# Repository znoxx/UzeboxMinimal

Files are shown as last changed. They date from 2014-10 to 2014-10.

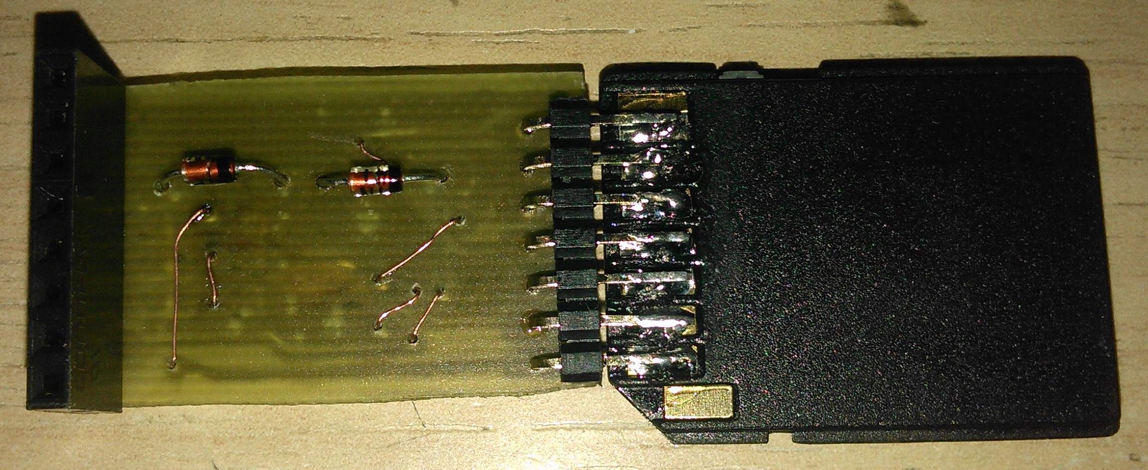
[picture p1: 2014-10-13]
sdcard/schematics/sdconnection2.jpg

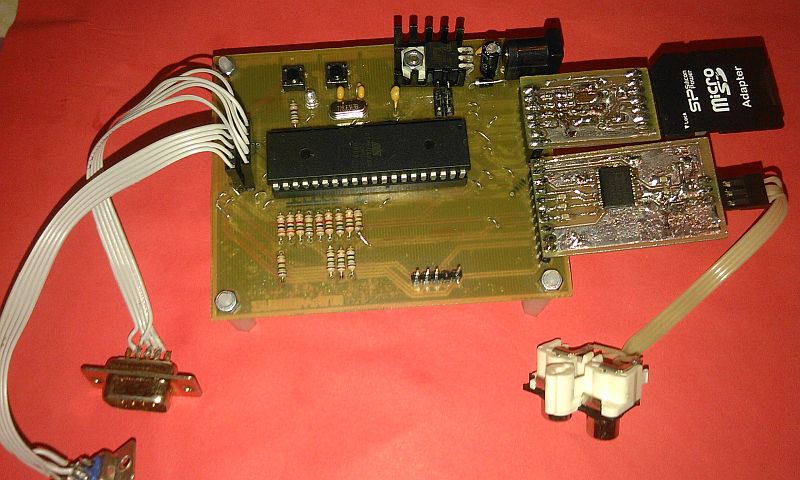
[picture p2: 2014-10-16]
_some_photos/assembled.jpg

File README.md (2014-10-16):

UzeboxMinimal
=============

Uzebox minimal design. The goal - to creat reprodusable modular design with minimal set of components.
Original project is located at http://uzebox.org

Update 16-Oct-2014 (2): Created simple MIDI expansion board. Never tested, since no MIDI devices owned :). See readme.txt inside midi subdir.
Actually project finalized.

Update 16-Oct-2014: Added video extension for AD725, same structure as in other projects (eagle,schematics,toner-transfer).
Also untested version removed.
Currently version is fully tested and confirmed working.

Update 13-Oct-2014: Added SD Card adapter.
eagle - To be opened with Eagle Cad 7.x.
schematics - Schematics, top jumpers and placement. Also an example of microSD adapter soldering. 
toner-transfer - Ready-to-print file for toner transfer. Have fun!
For best results:
Non-SDHC cards. In case using 2GB cards or bigger, create first partition about 256Mb. 
This is more, than enough for UzeBOX roms. 
Most important part partition should be FAT16 with 16K clusters.

Update 04-Oct-2014: This version is fixed somehow and soldered. Appears to be working.
Files (in mainboard dir):	
eagle - To be opened with Eagle Cad 7.x.
schematics - Schematics, top jumpers and placement
scart - connection via SCART
toner-transfer - Ready-to-print file for toner transfer. Have fun!

Update 01-Oct-2014: Current version is NOT tested in a "wild". Placed to share with forum members.
Files (not-tested dir):	
*.brd and *.sch - To be opened with Eagle Cad 7.x
schematics.pdf - Schematics
board-bottom.pdf - For toner transfer. Must be validated for correct size after/before print. Please check schematics/board layout for jumpers on top.

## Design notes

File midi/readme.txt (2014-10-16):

This midi extension daughterboard was never tested in wild.
Double check schematics with F2 revision of original UzeBox at http://belogic.com/uzebox/downloads.htm before crafting.
Feel free to report any issues.

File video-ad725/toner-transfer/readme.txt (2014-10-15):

After toner transfer, please remove toner trace near board connector to avoid short circuit.
Or, cut the paper exactly by dimensions.

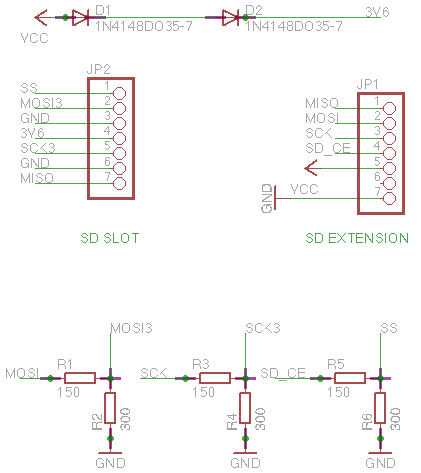
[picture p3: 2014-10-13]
sdcard/schematics/schematics.png

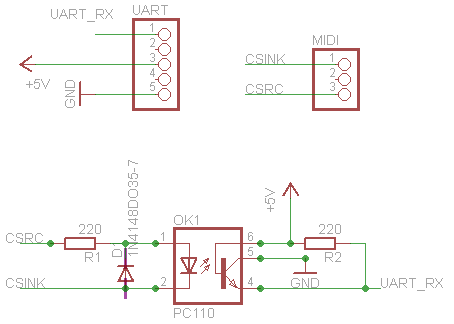
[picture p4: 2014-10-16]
midi/schematic/midi.png

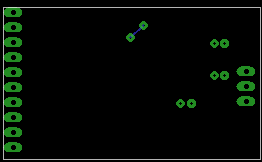
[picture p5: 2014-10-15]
video-ad725/schematics/jumpers.png

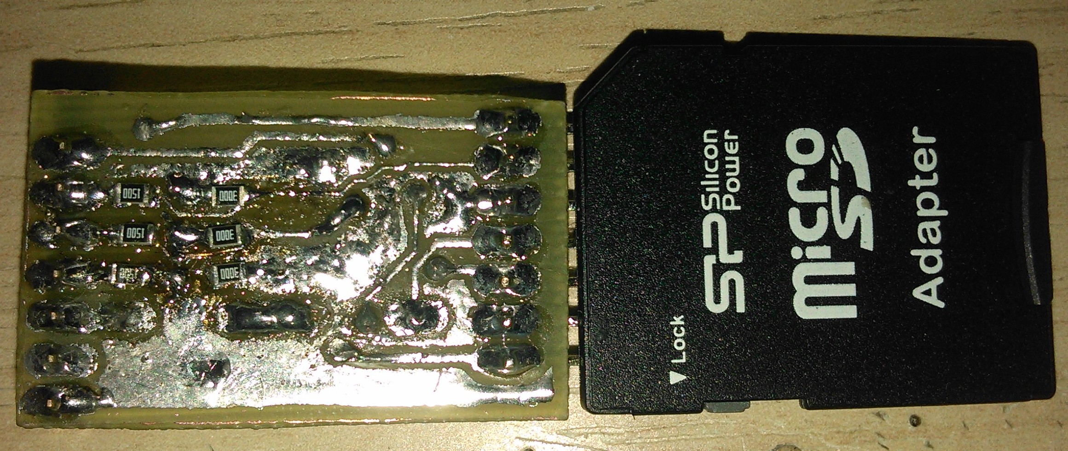
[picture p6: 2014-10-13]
sdcard/schematics/sdconnection1.jpg

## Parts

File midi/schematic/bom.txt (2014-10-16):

Part	Value	Type
D1	1N4148	Diode DO35-7
"R1,R2"	220 Ohm	Resistor 0.125w
OK1	PC110	Optocoupler DIL06
UART 	x10 male pinhead	2.54 mm
MIDI	"x3 male pinhead, central connector cut"	2.54 mm

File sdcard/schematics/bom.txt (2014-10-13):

Partlist

Exported from sdcard.brd at 13/10/14 22:13

EAGLE Version 7.1.0 Copyright (c) 1988-2014 CadSoft

Assembly variant: 

Part     Value          Package  Library  Position (mm)         Orientation

D1       1N4148DO35-7   DO35-7   diode    (9.8429 64.370853125) R180
D2       1N4148DO35-7   DO35-7   diode    (20.311653125 64.374278125) R180
JP1                     1X07     pinhead  (2.468659375 66.847653125) R270
JP2                     1X07     pinhead  (29.818525 69.15326875) R270
R1       150            R0805    resistor (6.523165625 71.8643625) R0
R2       300            R0805    resistor (12.27610625 71.891471875) R0
R3       150            R0805    resistor (6.53596875 69.4378125) R0
R4       300            R0805    resistor (12.279684375 69.417925) R0
R5       150            R0805    resistor (6.46664375 66.8897875) R0
R6       300            R0805    resistor (12.514678125 66.8897875) R180

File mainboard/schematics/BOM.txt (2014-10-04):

C1	Capacitor ceramic	330nf	1	
"C2,C3"	Capacitor ceramic	22pf	2	
C5	Capacitor ceramic	100nf	1	
C4	Capacitor electrolit	100mf	1	
IC1	ATMEGA644-20PU			
IC2	7805 Regulator		1	
"JP1,JP2,JP3,JP4,JP5"	PLS-40 connector		1	 cut it to pieces :)
LED1	LED	3mm	1	
Q1	Crystal	28.63636 Mhz	1	
D1	Diode	1N4001 	1	
J1	Powerjack			
"R1,R4,R12"	Resistor 0.125w	3K	4	
"R2,R5,R7"	Resistor 0.125w	1.5K	3	
"R3,R6,R8,R13"	Resistor 0.125w	750 Ohm	4	
R14	Resistor 0.125w	160 Ohm	1	
"R9,R10,R11"	Resistor 0.125w	75 Ohm	4	
"S1,S2"	Button		2

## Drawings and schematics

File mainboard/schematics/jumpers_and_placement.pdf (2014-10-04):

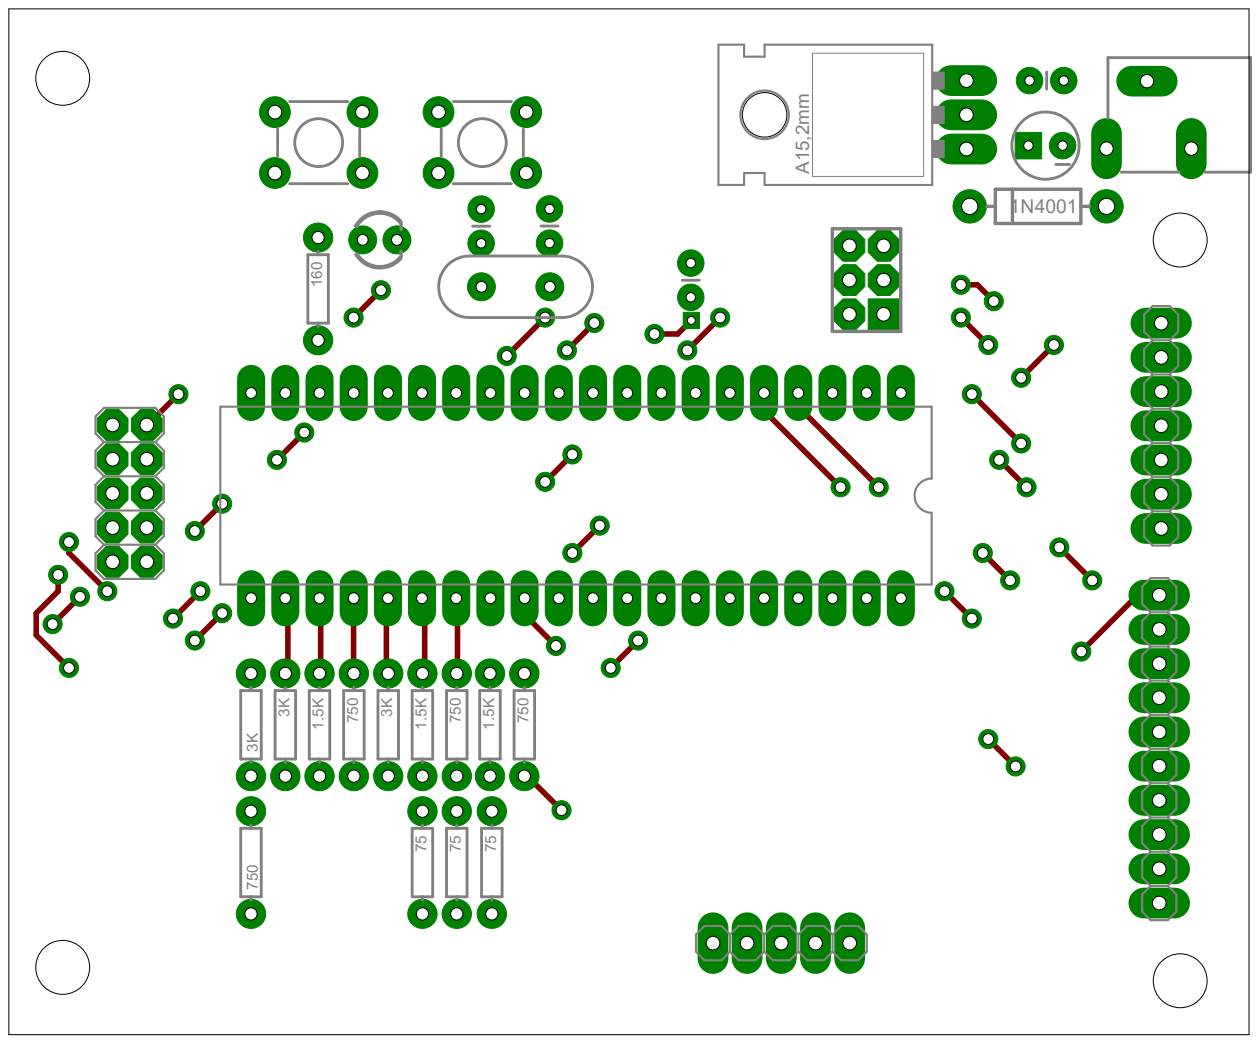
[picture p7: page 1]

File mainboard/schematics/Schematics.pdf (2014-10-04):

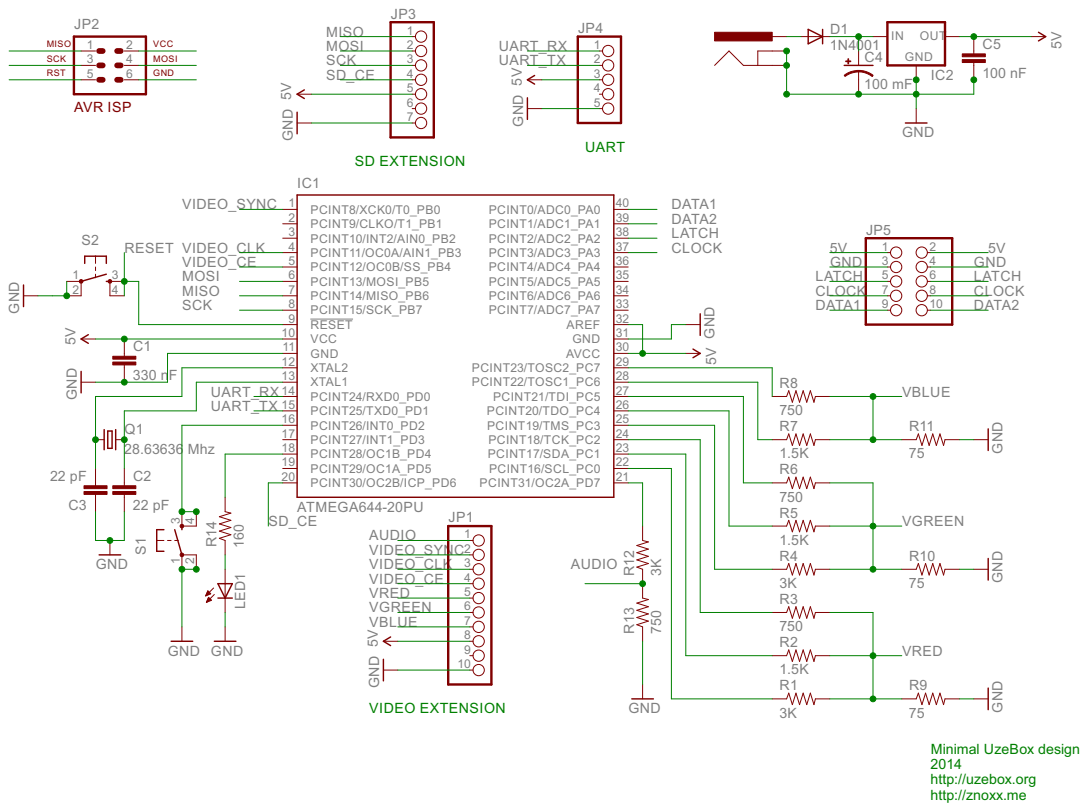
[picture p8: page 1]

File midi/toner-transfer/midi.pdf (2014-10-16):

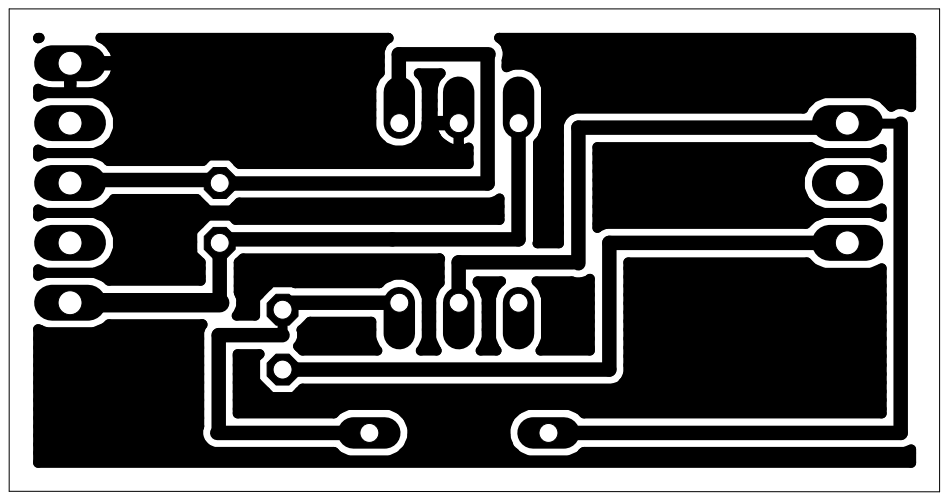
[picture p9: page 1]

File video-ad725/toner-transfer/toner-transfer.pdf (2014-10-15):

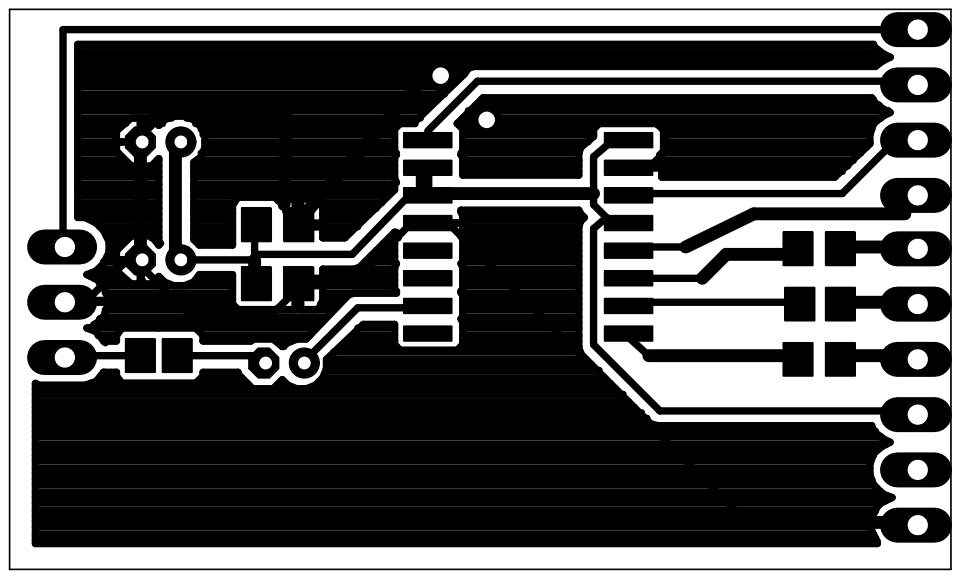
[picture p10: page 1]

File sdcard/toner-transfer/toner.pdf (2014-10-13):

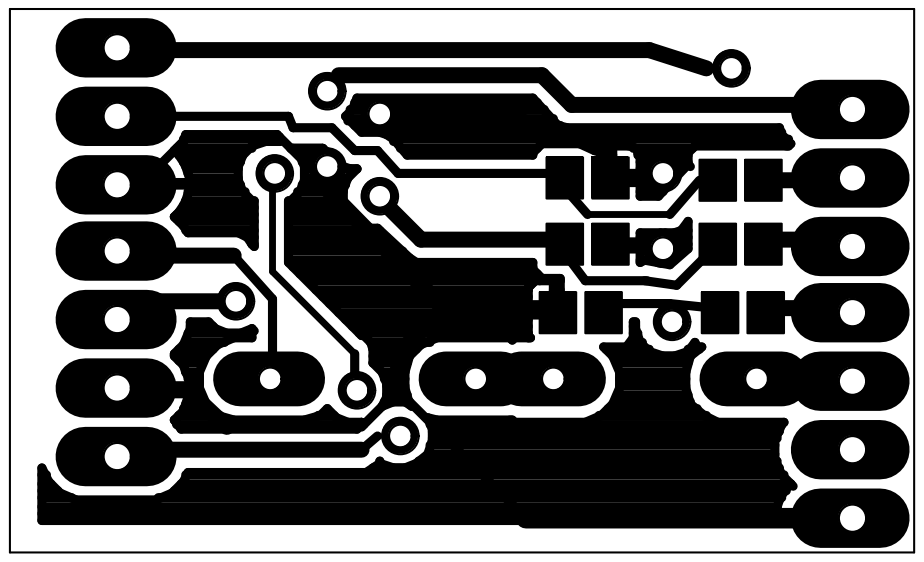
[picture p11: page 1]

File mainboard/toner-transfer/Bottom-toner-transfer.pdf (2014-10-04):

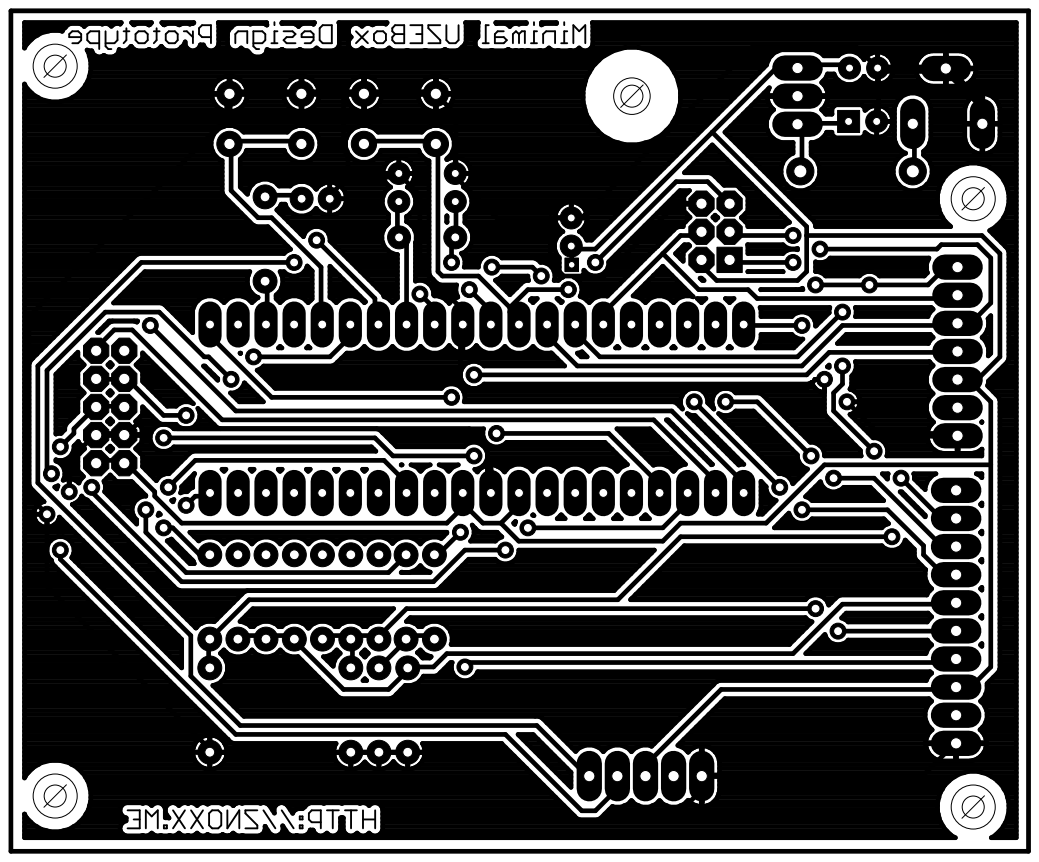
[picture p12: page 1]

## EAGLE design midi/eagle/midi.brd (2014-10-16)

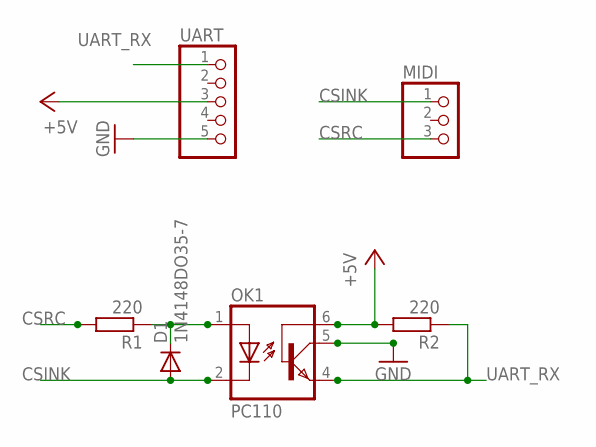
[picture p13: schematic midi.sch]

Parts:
D1: 1N4148DO35-7; DO35-7
MIDI: PINHD-1X3; 1X03
OK1: PC110; DIL06
R1, R2: 220; 0309V
UART: PINHD-1X5; 1X05

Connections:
+5V: OK1.6 (BAS), R2.2, UART.3
CSINK: D1.A, MIDI.1, OK1.2 (C)
CSRC: MIDI.3, R1.2
GND: OK1.5 (COL), UART.5
unnamed: D1.C, OK1.1 (A), R1.1
UART_RX: OK1.4 (EMI), R2.1, UART.1

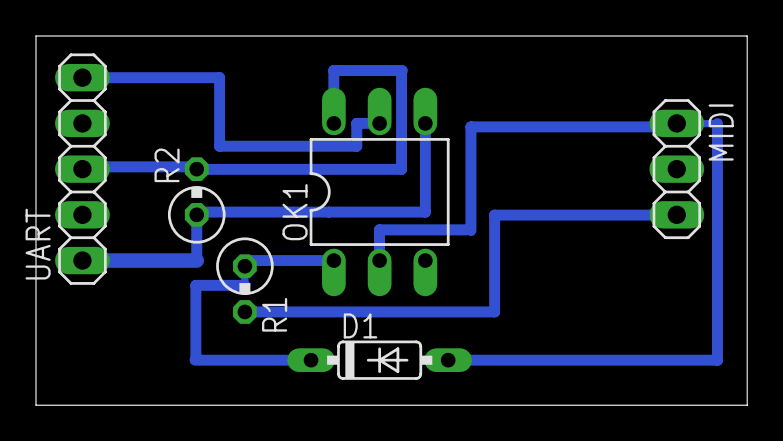
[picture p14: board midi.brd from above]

Board: 2 copper layers, 39.5 x 20.5 mm, 6 parts (0 on the bottom side), 6 nets.

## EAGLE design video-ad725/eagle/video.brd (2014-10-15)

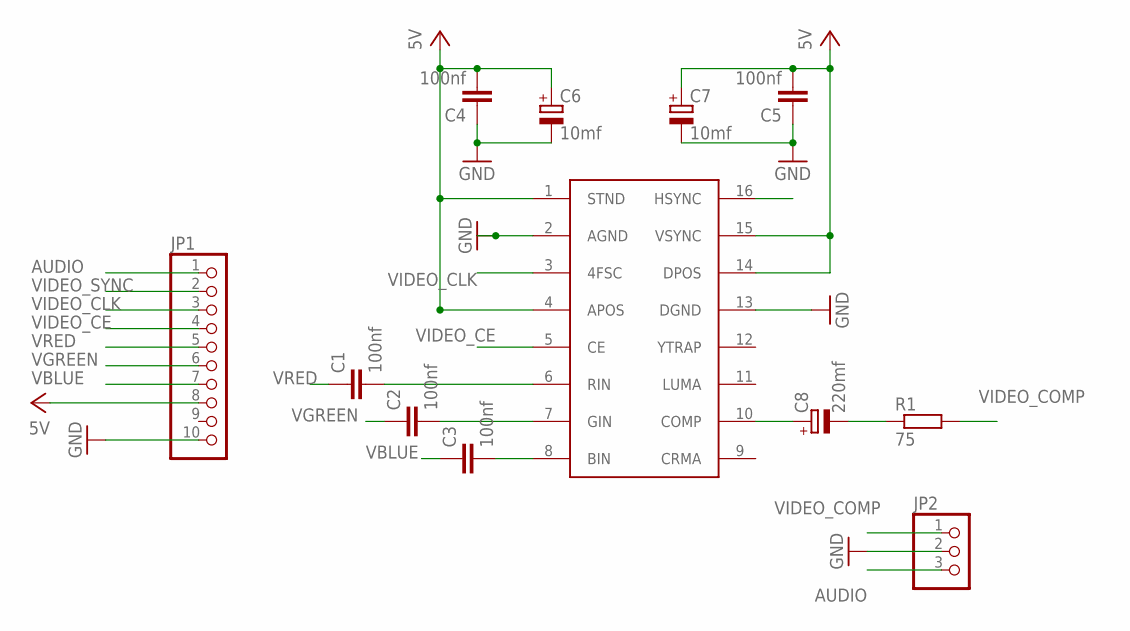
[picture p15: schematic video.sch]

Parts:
C1, C2, C3, C4, C5: 100nf; C0805
C6, C7: 10mf; E1,8-4
C8: 220mf; E1,8-4
JP1: PINHD-1X10; 1X10
JP2: PINHD-1X3; 1X03
R1: 75; R0805
U$1: AD725; SO16W

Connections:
AUDIO: JP1.1, JP2.3
GND: C4.1, C5.1, C6.-, C7.-, JP1.10, JP2.2, U$1.2 (AGND), U$1.13 (DGND)
unnamed: C1.2, U$1.6 (RIN)
unnamed: C2.2, U$1.7 (GIN)
unnamed: C3.2, U$1.8 (BIN)
unnamed: C8.+, U$1.10 (COMP)
unnamed: C8.-, R1.1
VBLUE: C3.1, JP1.7
VCC: C4.2, C5.2, C6.+, C7.+, JP1.8, U$1.1 (STND), U$1.4 (APOS), U$1.14 (DPOS), U$1.15 (VSYNC)
VGREEN: C2.1, JP1.6
VIDEO_CE: JP1.4, U$1.5 (CE)
VIDEO_CLK: JP1.3, U$1.3 (4FSC)
VIDEO_COMP: JP2.1, R1.2
VIDEO_SYNC: JP1.2, U$1.16 (HSYNC)
VRED: C1.1, JP1.5

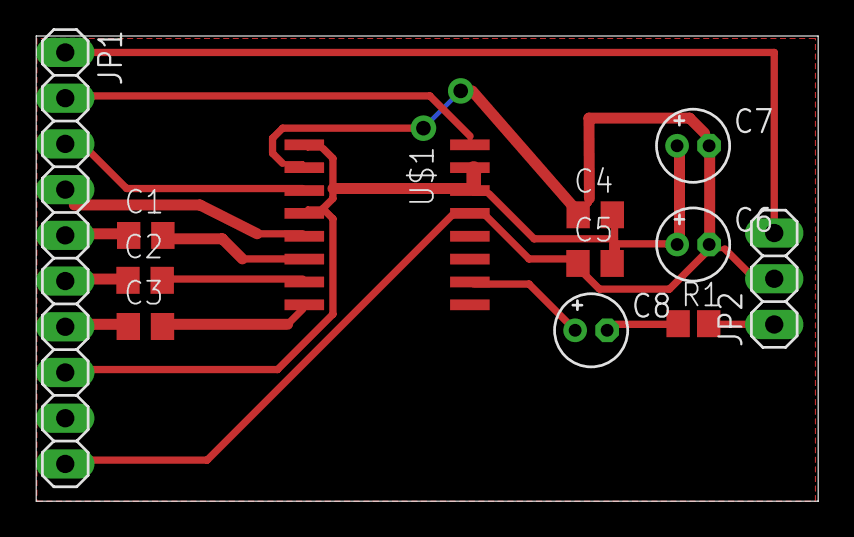
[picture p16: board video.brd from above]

Board: 2 copper layers, 43.4 x 25.8 mm, 12 parts (0 on the bottom side), 15 nets.

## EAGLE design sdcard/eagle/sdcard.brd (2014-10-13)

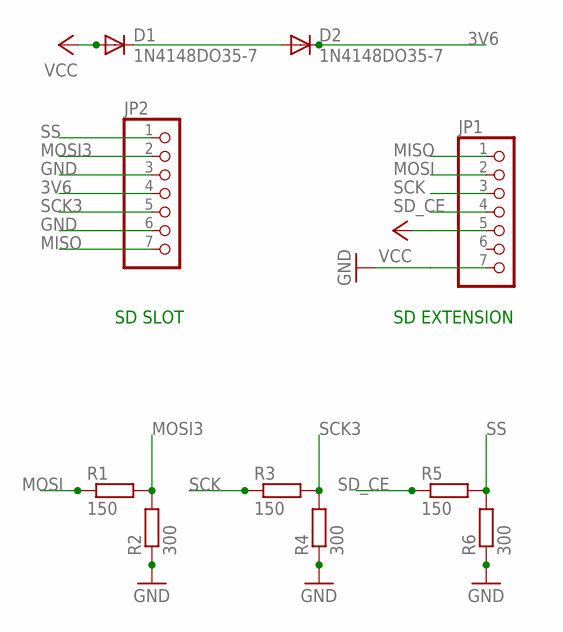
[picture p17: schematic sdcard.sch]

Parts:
D1, D2: 1N4148DO35-7; DO35-7
JP1, JP2: PINHD-1X7; 1X07
R1, R3, R5: 150; R0805
R2, R4, R6: 300; R0805

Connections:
3V6: D2.C, JP2.4
GND: JP1.7, JP2.3, JP2.6, R2.1, R4.1, R6.1
MISO: JP1.1, JP2.7
MOSI: JP1.2, R1.1
MOSI3: JP2.2, R1.2, R2.2
unnamed: D1.C, D2.A
SCK: JP1.3, R3.1
SCK3: JP2.5, R3.2, R4.2
SD_CE: JP1.4, R5.1
SS: JP2.1, R5.2, R6.2
VCC: D1.A, JP1.5

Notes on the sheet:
SD EXTENSION
SD SLOT

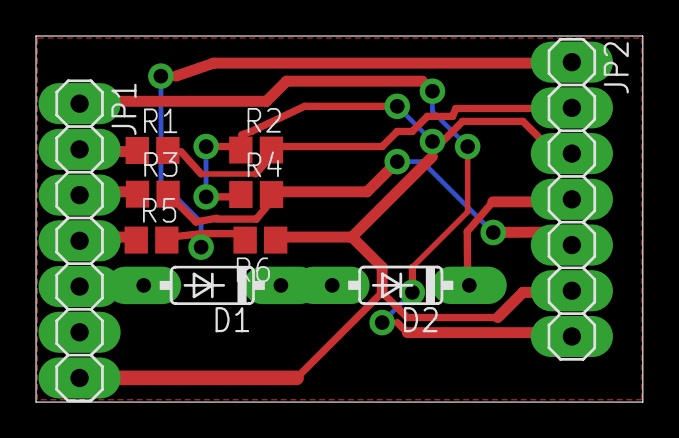
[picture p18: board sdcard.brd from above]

Board: 2 copper layers, 33.7 x 20.3 mm, 10 parts (0 on the bottom side), 11 nets.

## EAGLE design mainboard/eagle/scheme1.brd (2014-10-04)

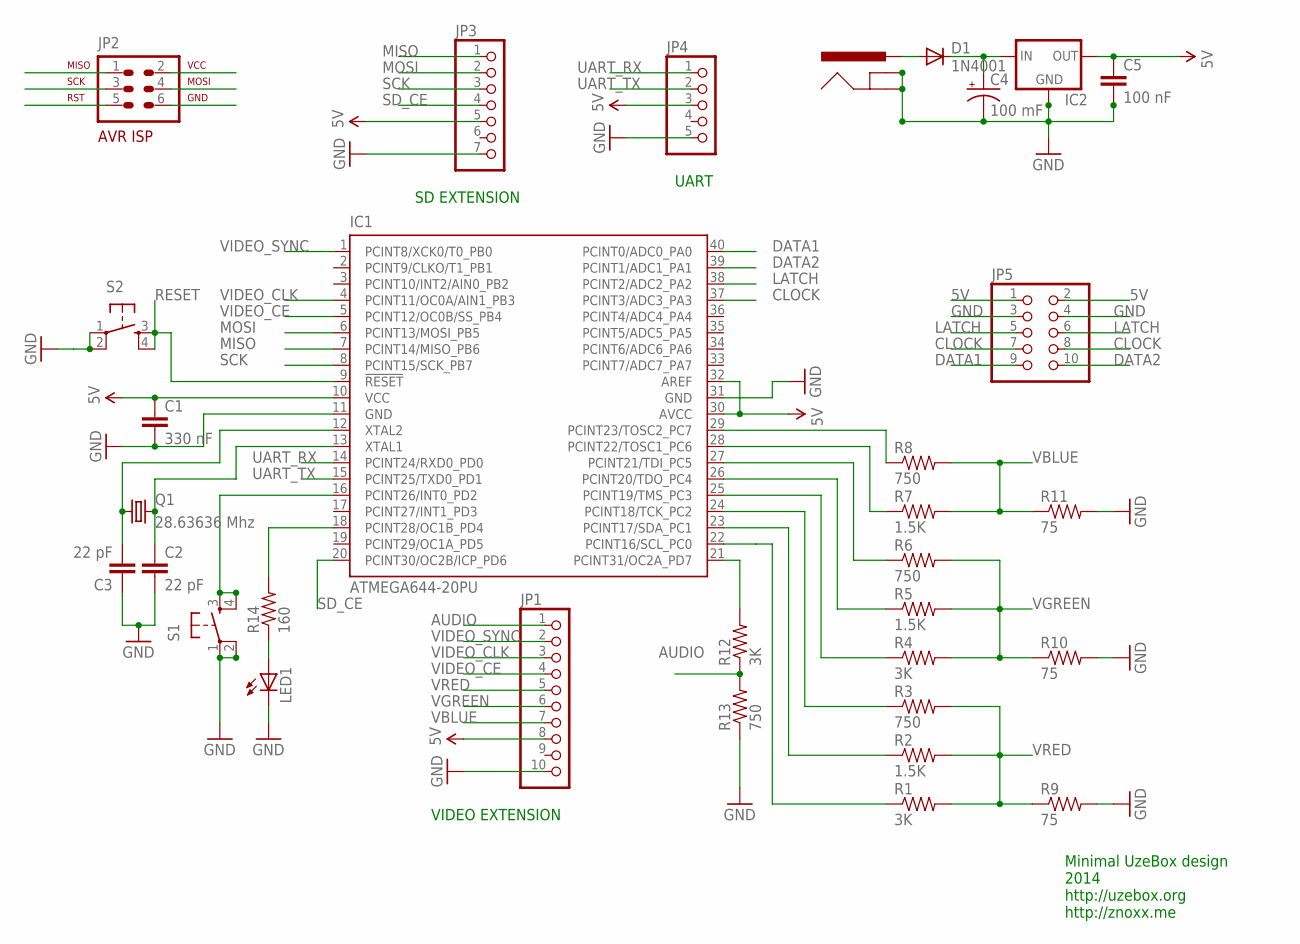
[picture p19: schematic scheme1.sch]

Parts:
C1: 330 nF; CAP-PTH-SMALL
C2, C3: 22 pF; CAP-PTH-SMALL
C4: 100 mF; CPOL-RADIAL-10UF-25V
C5: 100 nF; CAP-PTH-SMALL
D1: 1N4001; DIODE-1N4001
IC1: ATMEGA644-20PU; DIL40
IC2: V_REG_78XXSIDE; 78XXL
J1: POWER_JACKSLT; POWER_JACK_SLOT
JP1: PINHD-1X10; 1X10
JP2: AVR-ISP-6VERT; AVR-ISP-6
JP3: PINHD-1X7; 1X07
JP4: PINHD-1X5; 1X05
JP5: PINHD-2X5; 2X05
LED1: LED3MM
Q1: 28.63636 Mhz; HC49US
R1, R4, R12: 3K; AXIAL-0.3
R2, R5, R7: 1.5K; AXIAL-0.3
R3, R6, R8, R13: 750; AXIAL-0.3
R9, R10, R11: 75; AXIAL-0.3
R14: 160; AXIAL-0.3
S1, S2: TAC_SWITCHPTH; TACTILE-PTH

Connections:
5V: C1.1, C5.1, IC1.10 (VCC), IC1.30 (AVCC), IC1.32 (AREF), IC2.OUT, JP1.8, JP2.2, JP3.5, JP4.3, JP5.1, JP5.2
AUDIO: JP1.1, R12.P$1 (1), R13.P$2 (2)
CLOCK: IC1.37 (PCINT3/ADC3_PA3), JP5.7, JP5.8
DATA1: IC1.40 (PCINT0/ADC0_PA0), JP5.9
DATA2: IC1.39 (PCINT1/ADC1_PA1), JP5.10
GND: C1.2, C2.2, C3.1, C4.2 (-), C5.2, IC1.11 (GND), IC1.31 (GND), IC2.GND, J1.GND@1 (GNDBREAK), J1.GND@2 (GND), JP1.10, JP2.6, JP3.7, JP4.5, JP5.3, JP5.4, LED1.K (C), R9.P$2 (2), R10.P$2 (2), R11.P$2 (2), R13.P$1 (1), S1.1, S1.2, S2.1, S2.2
LATCH: IC1.38 (PCINT2/ADC2_PA2), JP5.5, JP5.6
MISO: IC1.7 (PCINT14/MISO_PB6), JP2.1, JP3.1
MOSI: IC1.6 (PCINT13/MOSI_PB5), JP2.4, JP3.2
unnamed: IC1.22 (PCINT16/SCL_PC0), R1.P$1 (1)
unnamed: IC1.23 (PCINT17/SDA_PC1), R2.P$1 (1)
unnamed: IC1.24 (PCINT18/TCK_PC2), R3.P$1 (1)
unnamed: C3.2, IC1.12 (XTAL2), Q1.1
unnamed: C2.1, IC1.13 (XTAL1), Q1.2
unnamed: IC1.25 (PCINT19/TMS_PC3), R4.P$1 (1)
unnamed: IC1.26 (PCINT20/TDO_PC4), R5.P$1 (1)
unnamed: IC1.27 (PCINT21/TDI_PC5), R6.P$1 (1)
unnamed: IC1.28 (PCINT22/TOSC1_PC6), R7.P$1 (1)
unnamed: IC1.29 (PCINT23/TOSC2_PC7), R8.P$1 (1)
unnamed: IC1.21 (PCINT31/OC2A_PD7), R12.P$2 (2)
unnamed: IC1.18 (PCINT28/OC1B_PD4), R14.P$2 (2)
unnamed: LED1.A, R14.P$1 (1)
unnamed: IC1.16 (PCINT26/INT0_PD2), S1.3, S1.4
unnamed: D1.A, J1.PWR
unnamed: C4.1 (+), D1.C, IC2.IN
RESET: IC1.9 (!RESET), JP2.5, S2.3, S2.4
SCK: IC1.8 (PCINT15/SCK_PB7), JP2.3, JP3.3
SD_CE: IC1.20 (PCINT30/OC2B/ICP_PD6), JP3.4
UART_RX: IC1.14 (PCINT24/RXD0_PD0), JP4.1
UART_TX: IC1.15 (PCINT25/TXD0_PD1), JP4.2
VBLUE: JP1.7, R7.P$2 (2), R8.P$2 (2), R11.P$1 (1)
VGREEN: JP1.6, R4.P$2 (2), R5.P$2 (2), R6.P$2 (2), R10.P$1 (1)
VIDEO_CE: IC1.5 (PCINT12/OC0B/SS_PB4), JP1.4
VIDEO_CLK: IC1.4 (PCINT11/OC0A/AIN1_PB3), JP1.3
VIDEO_SYNC: IC1.1 (PCINT8/XCK0/T0_PB0), JP1.2
VRED: JP1.5, R1.P$2 (2), R2.P$2 (2), R3.P$2 (2), R9.P$1 (1)

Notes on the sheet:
SD EXTENSION
UART
VIDEO EXTENSION
Minimal UzeBox design 2014 http://uzebox.org http://znoxx.me

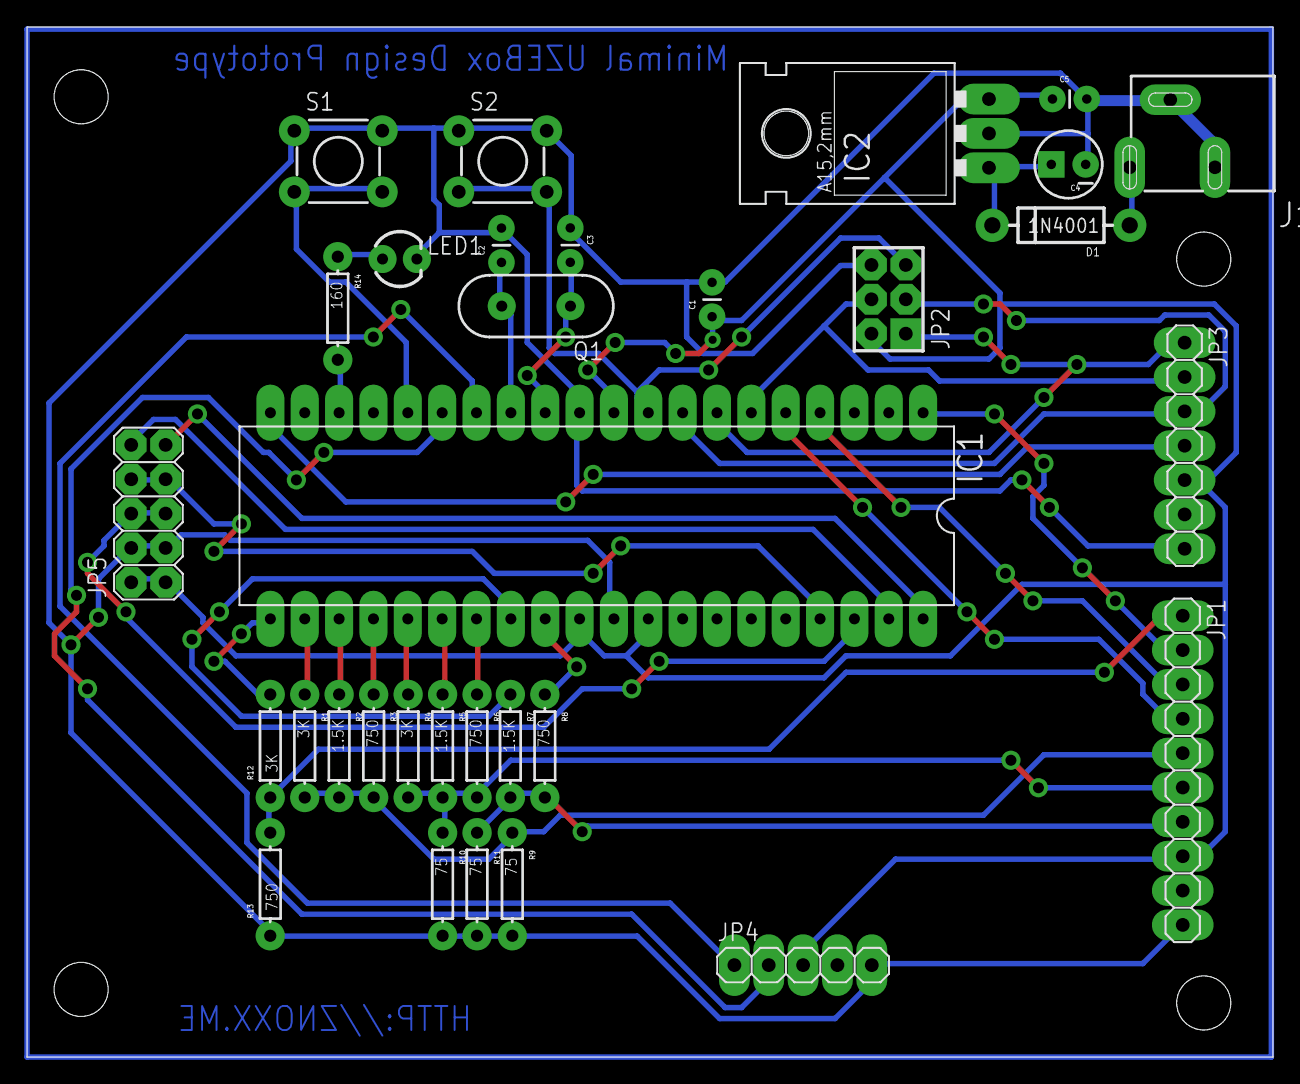
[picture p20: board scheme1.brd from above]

Board: 2 copper layers, 92.1 x 76.2 mm, 32 parts (0 on the bottom side), 36 nets.

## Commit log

2014-10-01 First untested version
    Eagle schematics, toner transfer PDF and pdf schematics
    [scheme1.brd, scheme1.sch]
2014-10-04 Fixed and validated version
    [scheme1.brd, scheme1.sch]
2014-10-13 SD card adapter
    Checked version of SDCard adaptor. Includes example of connection of
    microSD-card adapter
    [sdcard.brd, sdcard.sch]
2014-10-15 Added video extension board
    AD725 video extension, connected instead of SCART connector.
    [scheme1.brd, scheme1.sch, video.brd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]
2014-10-16 MIDI extension board
    Added MIDI extension board, untested version.
    [midi.brd, midi.sch]

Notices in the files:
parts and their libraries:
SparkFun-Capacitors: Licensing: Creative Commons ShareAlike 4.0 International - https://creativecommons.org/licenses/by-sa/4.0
